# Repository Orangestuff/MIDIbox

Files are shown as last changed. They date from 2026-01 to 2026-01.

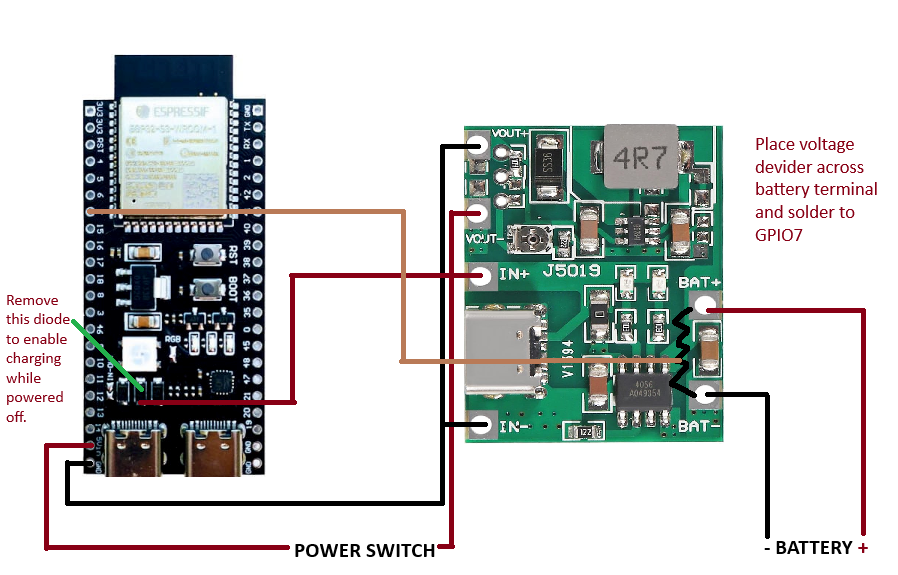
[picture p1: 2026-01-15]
images/schematic.png

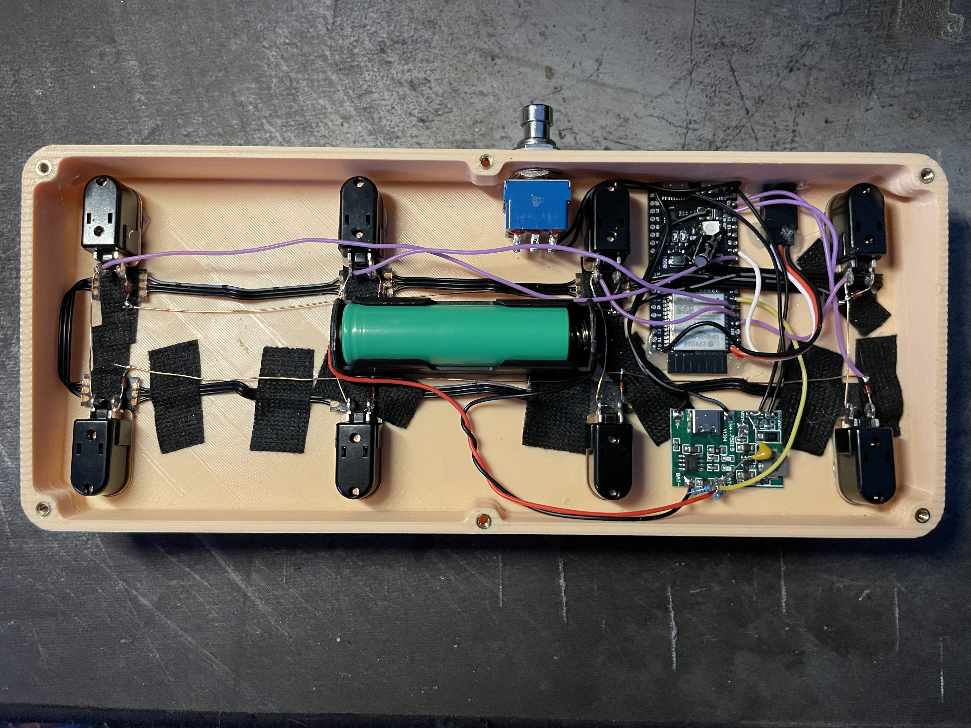
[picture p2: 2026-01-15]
images/build.JPG

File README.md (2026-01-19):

# ESP32-S3 Wireless MIDI Pedal

A fully programmable, battery-powered MIDI Foot Controller based on the ESP32-S3. This device supports **Bluetooth LE MIDI** and **USB MIDI** simultaneously, features a responsive **Web Interface** for configuration, and includes advanced **Power Management** for long battery life.

## 🚀 Key Features

### Connectivity

* **1000Hz Polling Rate:** Optimized "Fast Loop" architecture ensures ~1ms latency for note triggers.
* **Dual MIDI Interface:** Works over **Bluetooth LE (BLE)** and **USB** simultaneously.
* **Wireless Configuration:** Hosts a WiFi Access Point (`MidiBox_Config`) for on-the-fly editing via any smartphone or laptop.
* **Unique Identity Generation:** Hold **Switch 5 + Switch 8** on boot to generate a new BLE MAC address (useful for resolving pairing conflicts).

### Control & Logic

* **4 Programmable Banks:** Although the pedal has 8 physical footswitches, the software treats it as a 32-button controller divided into 4 "Pages" or "Banks". 
* **Advanced Switch Actions:**
* **Triggers:** Short Press, Long Press, and Release actions.
* **Message Types:** Note On/Off, CC, PC, Bank Up/Down, Direct Bank Select.
* **Logic Master:** Switches can trigger "None" (no MIDI) while still controlling other switches via groups.
* **Toggle Mode:** Latching behavior for CC or Note messages.

* **Grouping System:**
* **Exclusive Groups (Ex):** Pressing a switch turns OFF other switches in the same group (e.g., for channel switching).
* **Master/Slave Groups (Ld):** A "Master" switch can turn ON/OFF a defined set of "Slave" switches automatically.

### Expression Pedal

* **Per-Bank Configuration:** Different CC mappings and curves for every bank.
* **Smart Calibration:** "Set to Current" buttons in the Web UI for instant Min/Max calibration.
* **Response Curves:** Linear, Logarithmic (Fast Start), and Exponential (Swell).
* **Jitter Suppression:** Oversampling, hysteresis, and smoothing filters for stable output.

### Power & Presets

* **Deep Sleep:** Automatic low-power mode after inactivity.
* **Instant Wake:** Wakes up immediately upon pressing any footswitch.
* **Configurable:** Enable/Disable and set Timeout (1-120 mins) via Web UI.

* **Preset Manager:** Save and Load up to **5 Full Device Snapshots** (Setlists) to internal flash memory.
* **Battery Monitor:** Real-time voltage reading and low-battery LED warning.

---

## 🛠️ Hardware Bill of Materials (BOM)

| Component | Quantity | Description |
| --- | --- | --- |
| **Microcontroller** | 1 | ESP32-S3 DevKit (or similar S3 board) |
| **PSU/Battery Charger** | 1 | TP4056 Charger Module (or similar) |
| **Footswitches** | 8 | Momentary SPST Footswitches |
| **Power Switch** | 1 | Any SPST toggle switch |
| **LEDs** | 8 | WS2812B (Neopixel) individual LEDs or strip segments |
| **Expression Jack** | 1 | Servo extension wire |
| **Battery** | 1 | 3.7V 18650 Battery |
| **Resistors** | 3 | 2x100kΩ (For Battery Voltage Divider) 1x10kΩ (For Expression Pedal Pulldown) |
| **Diodes** | 8 | 1N4148 (For Switch Matrix - Optional but recommended) |
| **Enclosure** | 1 | 3D Printed Case (Files included in `/stl` folder) |
| **Threaded Inserts** | 6 | M3x4x5 Threaded Inserts (For pedalCaseV2.STL) |

## 🛠 Wiring & Pinout

The code is configured for an **ESP32-S3** using a 2x4 Switch Matrix.

| Component | ESP32-S3 Pin | Notes |
| --- | --- | --- |
| **Switch Row 1** | GPIO 12 | Matrix Output |
| **Switch Row 2** | GPIO 13 | Matrix Output |
| **Switch Col 1** | GPIO 4 | Matrix Input (Pull-up) |
| **Switch Col 2** | GPIO 5 | Matrix Input (Pull-up) |
| **Switch Col 3** | GPIO 6 | Matrix Input (Pull-up) |
| **Switch Col 4** | GPIO 8 | Matrix Input (Pull-up) |
| **LED Strip** | GPIO 48 | WS2812B / NeoPixel (9 LEDs) |
| **Battery Sense** | GPIO 7 | Voltage Divider (ADC1 Ch 6) |
| **Expression** | GPIO 2 | TRS Tip (ADC1 Ch 2) |

> **LED Wiring Note:** The LEDs require a "Snake" wiring pattern for the default mapping:
> `Sw1 -> Sw2 -> Sw3 -> Sw4 -> Sw8 -> Sw7 -> Sw6 -> Sw5`

**Note:** The Expression Pedal input expects a voltage divider setup (3.3V -> Pot -> GND, Wiper to GPIO 2).

## ⚡ Optional Hardware Mod: Offline Charging

By default, the ESP32 draws power and boots up whenever a USB cable is connected, even if the intention is only to charge the battery.

To enable **Offline Charging** (charging the battery via USB while the main unit remains powered down), you can remove the VBUS blocking diode (typically labeled **D1** or similar on the PCB).

* **Action:** Desolder and remove the Schottky diode on the 5V rail.
* **Result:** The USB connection will power the battery management circuit exclusively. The ESP32 will not boot until the main power switch is toggled ON.

## 🖨️ 3D Printed Case

This repository includes STL files for a custom enclosure designed to fit the electronics and switches perfectly.

* **pedalCaseV2.STL:** Holds all electronics.
* **baseplateV2.STL:** mount with M3 screws and threaded inserts.
* 
---

## 💾 Installation

1. **Environment:** Requires **ESP-IDF v5.x** (Tested with v5.5.1).
2. **Dependencies:**
* `tinyusb` (Component via IDF Component Manager)
* `driver/rtc_io` (Standard in IDF)

3. **Configuration:**
* Enable **TinyUSB** in `menuconfig`.
* Set partition table to accommodate NVS data (factory/app partitions).

4. **Flash:**
```bash
idf.py build flash monitor

```

---

## 📖 User Manual

### 1. Basic Operation

* **Power On:** The LEDs will flash the current Bank Color.
* **Change Banks:** Use configured "Bank Up/Down" switches or bind banks directly.
* *Bank 1: Red | Bank 2: Green | Bank 3: Blue | Bank 4: Purple*

* **Battery Status:** LED 1 indicates level:
* 🟢 > 3.9V (Good)
* 🟡 > 3.6V (Okay)
* 🔴 < 3.6V (Low)

### 2. Configuration Mode (WiFi)

1. If no known WiFi is found, the pedal broadcasts an Access Point:
* **SSID:** `MidiBox_Config`
* **Pass:** `12345678`

2. Connect your phone/laptop to this network.
3. Open a browser to `http://192.168.4.1`.
4. **Important:** Changes made in the UI are live in RAM. Click **"Save All Configuration"** to persist them to flash.

### 3. Preset Manager

Located in the Web UI:

* **Save:** Enter a name in the text box and click **SAVE**. This takes a snapshot of the *current* state (Bank settings, Expressions, etc.) and stores it in a slot.
* **Load:** Select a preset from the dropdown and click **LOAD**. The pedal immediately reconfigures itself.
* *Note: The browser remembers your last used preset ID for convenience.*

### 4. Deep Sleep

* The device sleeps after the configured idle time (Default: 5 mins).
* **To Wake:** simply step on **ANY** switch. The pedal wakes instantly and flashes the LEDs to confirm readiness.
* **Optimization:** The startup sequence prioritizes LED feedback before initializing WiFi/USB, making the wake-up feel instantaneous.

---

## 🧩 Advanced Logic Guide

The Web UI allows complex interactions between switches using **Masks**:

* **Exclusive Mask (Ex / 🛡️):**
* Assign switches to a "Group Number" (1-8).
* If Switch A and Switch B share Group 1, pressing A will automatically turn B **OFF**.
* *Usage: Guitar Amp Channel switching (Clean vs Distortion).*

* **Lead/Master Mask (Ld / ⚡):**
* If Switch A is the "Master" of Group 1, and Switch B "Includes" (🔗) Group 1...
* Pressing A will force B to turn **ON**.
* Releasing A (or turning it off) will force B to turn **OFF**.
* *Usage: A "Solo" switch that turns on Delay + Boost + Reverb simultaneously.*

---

## 📂 Project Structure

* `main.c` - Core logic, BLE stack, USB stack, GPIO matrix scanning, Sleep logic.
* `index.h` - HTML/CSS/JS for the Web Interface (gzipped string or raw string).
* `CMakeLists.txt` - Build configuration.

---

## ⚠️ Troubleshooting

* **Pedal won't wake up:** Ensure battery is charged (>3.0V).
* **Cannot find Bluetooth:** Hold **Switch 5 + 8** while powering on to generate a new MAC address. The LEDs will flash purple.
* **Expression Pedal Jitter:** Increase `EXP_HYSTERESIS` in `main.c` or use the Web UI to re-calibrate Min/Max values.
* **"Save Error" in Web UI:** Ensure you are not spamming the save button; writing to NVS takes ~200-500ms.

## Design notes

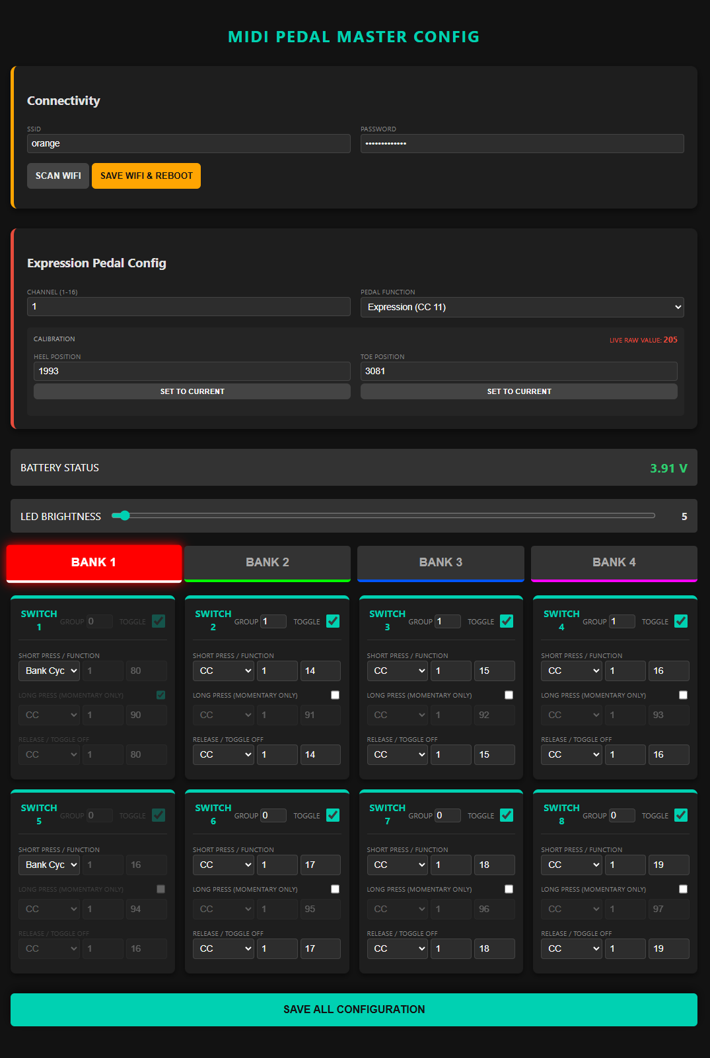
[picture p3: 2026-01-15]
images/config.png

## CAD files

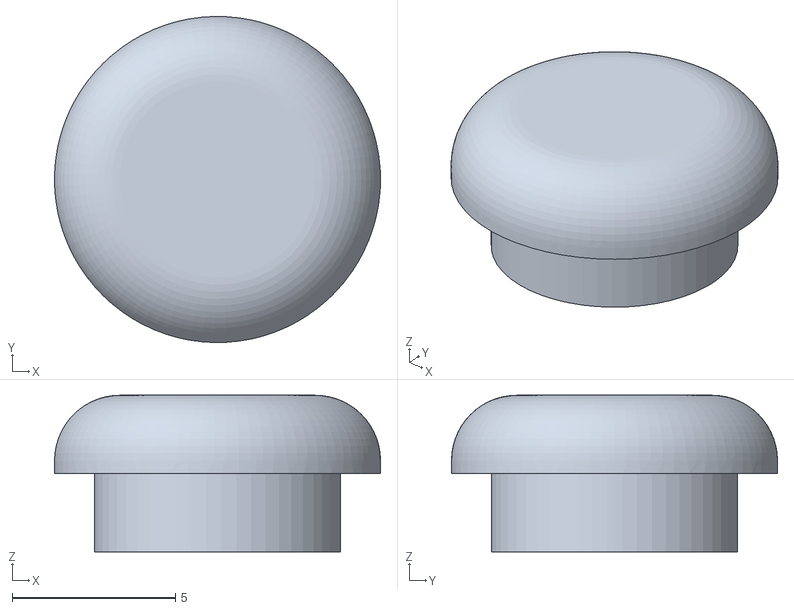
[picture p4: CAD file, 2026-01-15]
stl/LEDwindow.STL
10.0 x 10.00 x 4.80

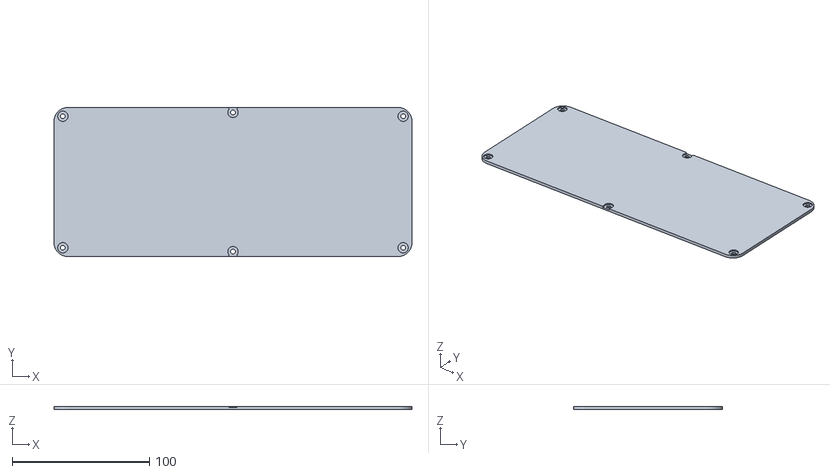
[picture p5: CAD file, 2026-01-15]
stl/baseplateV2.STL
260.5 x 108.4 x 2.40

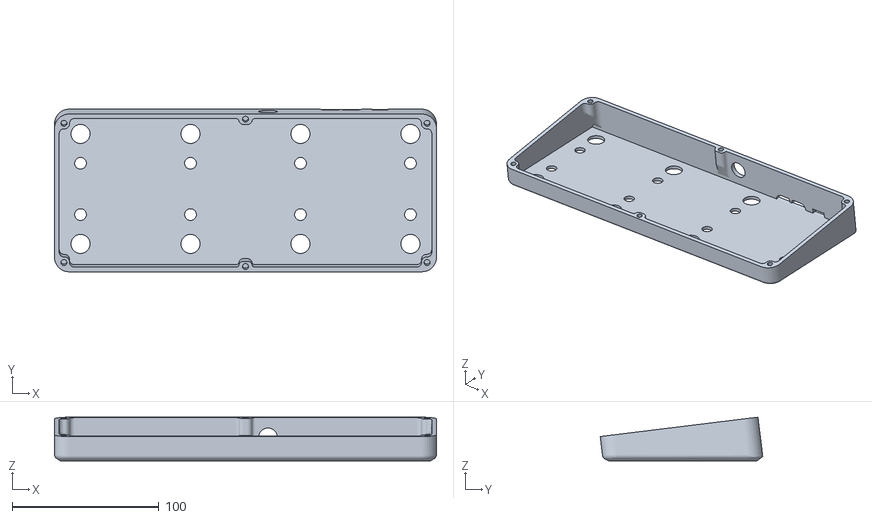
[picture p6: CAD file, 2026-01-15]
stl/pedalCaseV2.STL
260.5 x 110.9 x 29.8

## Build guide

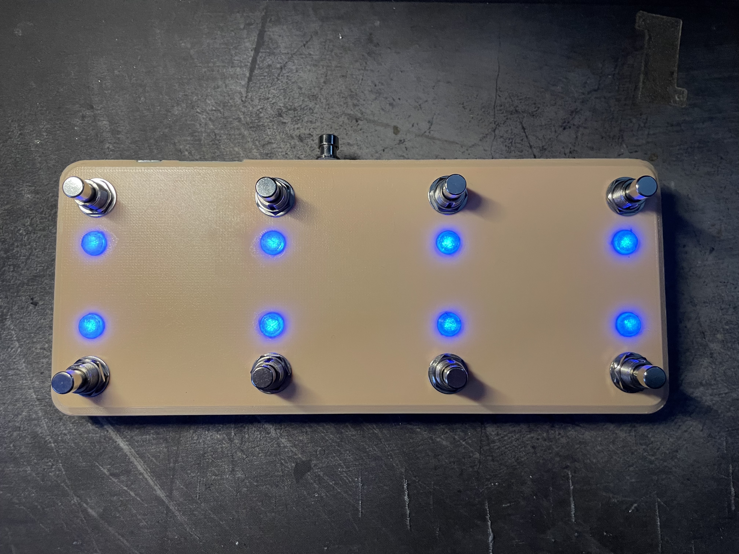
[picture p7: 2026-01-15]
images/build2.JPG

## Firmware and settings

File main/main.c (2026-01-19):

#include <stdio.h>
#include <string.h>
#include <stdlib.h>
#include <ctype.h>
#include <math.h>
#include <sys/param.h>

#include "esp_wifi.h"
#include "esp_http_server.h"
#include "esp_log.h"
#include "nvs_flash.h"
#include "driver/gpio.h"
#include "driver/rmt.h"
#include "tinyusb.h"
#include "tinyusb_default_config.h"
#include "cJSON.h"
#include "index.h"
#include "freertos/queue.h"
#include "freertos/event_groups.h"
#include "esp_system.h"
#include "esp_random.h"
#include "esp_mac.h"
#include "esp_timer.h"
#include "esp_sleep.h" // NEW: Required for Deep Sleep
#include "driver/rtc_io.h"
// --- ADC Headers ---
#include "esp_adc/adc_oneshot.h"

// --- BLE Headers ---
#include "esp_bt.h"
#include "esp_bt_main.h"
#include "esp_gap_ble_api.h"
#include "esp_gatts_api.h"
#include "esp_bt_defs.h"

static const char *TAG = "MIDI_PEDAL";

// --- CONFIGURATION ---
#define SWITCH_COUNT 8
#define BANK_COUNT 4
#define LONG_PRESS_MS 1200
#define DEEP_SLEEP_TIMEOUT_MS 30000 //30000 NEW: 5 Minutes
#define MIDI_NOTE_OFF 128
#define MIDI_NOTE_ON  144
#define MIDI_CC       176
#define MIDI_PC       192

#define LED_DATA_PIN 48
#define LED_COUNT 9
#define BATTERY_LED_INDEX 0

// --- EXPRESSION PEDAL CONFIG ---
#define EX_PEDAL_CHANNEL ADC_CHANNEL_2 
#define EX_SMOOTH_SIZE   10
#define EXP_HYSTERESIS   15

// --- BATTERY CONFIG (GPIO 7 / ADC1) ---
#define BAT_ADC_CHANNEL ADC_CHANNEL_6 
#define BAT_ADC_UNIT    ADC_UNIT_1    
#define BAT_DIVIDER_RATIO 2.0f 
#define BAT_MAX_V 4.2f
#define BAT_MIN_V 3.0f

#define WIFI_CONNECTED_BIT BIT0
#define WIFI_FAIL_BIT      BIT1
#define COMBO_HOLD_MS 2000

// --- MATRIX CONFIG ---
#define NUM_ROWS 2
#define NUM_COLS 4

const gpio_num_t ROW_PINS[NUM_ROWS] = { GPIO_NUM_12, GPIO_NUM_13 };
const gpio_num_t COL_PINS[NUM_COLS] = { GPIO_NUM_4, GPIO_NUM_5, GPIO_NUM_6, GPIO_NUM_8};

const int MATRIX_MAP[NUM_ROWS][NUM_COLS] = {
    {0, 1, 2, 3}, 
    {4, 5, 6, 7}  
};

// --- BLE MIDI UUIDs ---
#define MIDI_SERVICE_UUID        0x03, 0xB8, 0x0E, 0x5A, 0xED, 0xE8, 0x4B, 0x33, 0xA7, 0x51, 0x6C, 0xE3, 0x4E, 0xC4, 0xC7, 0x00
#define MIDI_CHARACTERISTIC_UUID 0x77, 0x72, 0xE5, 0xDB, 0x38, 0x68, 0x41, 0x12, 0xA1, 0xA9, 0xF2, 0x66, 0x9D, 0x10, 0x6B, 0xF3

// --- GLOBALS ---
uint8_t led_strip_pixels[LED_COUNT][3];
static float g_bat_voltage = 0.0f;
static volatile bool is_scanning = false; 
static esp_bd_addr_t current_mac_addr; 
static adc_oneshot_unit_handle_t adc_handle = NULL;
static float smoothed_bat = 0.0f;
static uint32_t last_activity_time = 0; // NEW: Activity Timer

volatile int g_exp_raw_val = 0; 

typedef struct { char ssid[32]; char pass[64]; } wifi_cfg_t;

// --- STRUCTS ---

typedef struct {
    uint8_t chan;
    uint8_t cc;
    uint16_t min;   
    uint16_t max;   
    uint8_t curve;  
} exp_cfg_t;

typedef struct { 
    uint8_t p_type; uint8_t p_chan; uint8_t p_d1; uint8_t p_edge;
    uint8_t lp_type; uint8_t lp_chan; uint8_t lp_d1; 
    uint8_t l_type; uint8_t l_chan; uint8_t l_d1; 
    
    uint8_t p_excl; uint8_t p_master; 
    uint8_t lp_excl; uint8_t lp_master;
    uint8_t l_excl; uint8_t l_master;

    uint8_t incl_mask; 
    uint8_t lp_enabled; 
    uint8_t toggle_mode; 
} sw_cfg_t;

typedef struct {
    sw_cfg_t switches[SWITCH_COUNT];
    exp_cfg_t exp; 
} bank_cfg_t;

typedef struct {
    uint8_t current_bank;
    uint8_t global_brightness;
    uint8_t sw6_cycle_rev;
    uint8_t sw7_cycle_fwd;
    uint8_t deep_sleep_en; 
    uint8_t deep_sleep_mins; 
    bank_cfg_t banks[BANK_COUNT];
} device_cfg_t; 

wifi_cfg_t w_cfg;
volatile device_cfg_t dev_cfg; 
static QueueHandle_t save_queue = NULL;
static EventGroupHandle_t s_wifi_event_group;
static httpd_handle_t srv = NULL;
static bool is_wifi_on = false;

//Preset Struct
#define MAX_PRESETS 5
typedef struct {
    char name[32];
    bool active;
    device_cfg_t data; // Stores the entire device state
} preset_t;
preset_t presets[MAX_PRESETS];
const uint8_t BANK_COLORS[4][3] = { {255,0,0}, {0,255,0}, {0,0,255}, {255,0,255} };

// Forward Declarations
void nvs_save_presets_to_flash();
void midi_task(void *pv);
void restart_task(void *p);
void wifi_init_task(void *pv); 
esp_err_t get_page(httpd_req_t *req);
esp_err_t get_json(httpd_req_t *req);
esp_err_t get_status(httpd_req_t *req);
esp_err_t post_save(httpd_req_t *req);
esp_err_t post_set_bank(httpd_req_t *req);
esp_err_t post_save_wifi(httpd_req_t *req);
esp_err_t get_wifi_scan(httpd_req_t *req);
void set_pixel(int index, uint8_t r, uint8_t g, uint8_t b);
void refresh_leds();
void set_wifi_mode(bool enable);
void init_battery();
void read_battery();
void send_midi_msg(uint8_t type, uint8_t chan, uint8_t val, uint8_t velocity);
static void wifi_event_handler(void* arg, esp_event_base_t event_base, int32_t event_id, void* event_data);

// --- USB DESCRIPTORS ---
enum { ITF_NUM_MIDI = 0, ITF_NUM_MIDI_STREAMING, ITF_COUNT };
enum { EPNUM_MIDI = 1 };
#define TUSB_DESCRIPTOR_TOTAL_LEN (TUD_CONFIG_DESC_LEN + TUD_MIDI_DESC_LEN)
static const char* s_str_desc[5] = {(char[]){0x09, 0x04}, "TinyUSB", "MidiBox", "123456", "MIDI Interface"};
static const uint8_t s_midi_cfg_desc[] = {
    TUD_CONFIG_DESCRIPTOR(1, ITF_COUNT, 0, TUSB_DESCRIPTOR_TOTAL_LEN, 0x00, 100),
    TUD_MIDI_DESCRIPTOR(ITF_NUM_MIDI, 4, EPNUM_MIDI, 0x80 | EPNUM_MIDI, 64),
};

// ==========================================================
//             BATTERY & EXPRESSION LOGIC (ADC1)
// ==========================================================
void init_battery() {
    adc_oneshot_unit_init_cfg_t init_config = { .unit_id = BAT_ADC_UNIT };
    if (adc_handle == NULL) {
        adc_oneshot_new_unit(&init_config, &adc_handle);
    }
    if (adc_handle) {
        adc_oneshot_chan_cfg_t config = { .bitwidth = ADC_BITWIDTH_DEFAULT, .atten = ADC_ATTEN_DB_12 };
        adc_oneshot_config_channel(adc_handle, BAT_ADC_CHANNEL, &config);
        
        int raw = 0;
        if (adc_oneshot_read(adc_handle, BAT_ADC_CHANNEL, &raw) == ESP_OK) {
            float pin_voltage = (raw / 4095.0f) * 3.3f; 
            smoothed_bat = pin_voltage * BAT_DIVIDER_RATIO;
        }
    }
}

void init_expression_pedal() {
    if (adc_handle == NULL) {
        adc_oneshot_unit_init_cfg_t init_config = { .unit_id = BAT_ADC_UNIT };
        adc_oneshot_new_unit(&init_config, &adc_handle);
    }
    
    if (adc_handle) {
        adc_oneshot_chan_cfg_t config = {
            .bitwidth = ADC_BITWIDTH_12, 
            .atten = ADC_ATTEN_DB_12,    
        };
        adc_oneshot_config_channel(adc_handle, EX_PEDAL_CHANNEL, &config);
    }
}

void read_battery() {
    if (adc_handle == NULL) return;
    int raw = 0;
    if (adc_oneshot_read(adc_handle, BAT_ADC_CHANNEL, &raw) == ESP_OK) {
        float pin_voltage = (raw / 4095.0f) * 3.3f; 
        float instant_voltage = pin_voltage * BAT_DIVIDER_RATIO;
        if (smoothed_bat < 0.1f) smoothed_bat = instant_voltage; 
        else smoothed_bat = (smoothed_bat * 0.98f) + (instant_voltage * 0.02f);
        g_bat_voltage = smoothed_bat;
    }
}

// Helper for Curve Math
uint8_t apply_curve(float normalized, uint8_t type) {
    float val = normalized;
    if (val < 0.0f) val = 0.0f;
    if (val > 1.0f) val = 1.0f;

    switch(type) {
        case 1: val = val * val; break;
        case 2: val = sqrtf(val); break;
        case 0: default: break;
    }
    return (uint8_t)(val * 127.0f);
}

// Change the function signature to accept the time
void process_expression_pedal(uint32_t now_ms) {
    volatile exp_cfg_t *exp = &dev_cfg.banks[dev_cfg.current_bank].exp;

    // ... [Keep ADC reading, Hysteresis, Smoothing, and Normalization code exactly the same] ...
    // ... [Copy lines 240-275 from your current file here] ...
    
    // Oversampling
    uint32_t sum = 0;
    int sample = 0;
    for(int i=0; i<4; i++) {
        adc_oneshot_read(adc_handle, EX_PEDAL_CHANNEL, &sample);
        sum += sample;
    }
    int raw = sum / 4;

    // Hysteresis
    static int stable_raw = 0;
    if (raw > (stable_raw + EXP_HYSTERESIS)) { stable_raw = raw - EXP_HYSTERESIS; } 
    else if (raw < (stable_raw - EXP_HYSTERESIS)) { stable_raw = raw + EXP_HYSTERESIS; }

    // Smoothing
    static float smooth_raw = 0;
    smooth_raw = (smooth_raw * 0.90f) + ((float)stable_raw * 0.10f);
    int current_val = (int)smooth_raw;

    // Update UI Global
    g_exp_raw_val = current_val; 

    // Normalize
    float norm = 0.0f;
    if (exp->max > exp->min) {
        norm = (float)(current_val - exp->min) / (float)(exp->max - exp->min);
    } else {
        norm = (float)(exp->min - current_val) / (float)(exp->min - exp->max);
    }
    if (norm < 0.0f) norm = 0.0f;
    if (norm > 1.0f) norm = 1.0f;

    uint8_t midi_val = apply_curve(norm, exp->curve);

    static uint8_t last_exp_val = 255;
    static uint8_t last_bank_idx = 255; 

    if (midi_val != last_exp_val || dev_cfg.current_bank != last_bank_idx) {
        send_midi_msg(176, exp->chan, exp->cc, midi_val); 
        last_exp_val = midi_val;
        last_bank_idx = dev_cfg.current_bank;
        
        // FIX: Use the synchronized time passed from the main loop
        last_activity_time = now_ms;
    }
}

// ==========================================================
//             BLE MIDI STACK
// ==========================================================
static bool is_ble_connected = false;
static uint16_t current_conn_id = 0;        
static esp_gatt_if_t current_gatts_if = 0;
static uint16_t midi_char_handle = 0; 

static const uint8_t midi_service_uuid[16] = { 0x00, 0xC7, 0xC4, 0x4E, 0xE3, 0x6C, 0x51, 0xA7, 0x33, 0x4B, 0xE8, 0xED, 0x5A, 0x0E, 0xB8, 0x03 };
static const uint8_t midi_char_uuid[16]    = { 0xF3, 0x6B, 0x10, 0x9D, 0x66, 0xF2, 0xA9, 0xA1, 0x12, 0x41, 0x68, 0x38, 0xDB, 0xE5, 0x72, 0x77 };

enum { MIDI_IDX_SVC, MIDI_IDX_CHAR, MIDI_IDX_VAL, MIDI_IDX_CFG, MIDI_IDX_NB };

static esp_ble_adv_params_t adv_params = {
    .adv_int_min        = 0x20,
    .adv_int_max        = 0x40,
    .adv_type           = ADV_TYPE_IND,
    .own_addr_type      = BLE_ADDR_TYPE_RANDOM, 
    .channel_map        = ADV_CHNL_ALL,
    .adv_filter_policy  = ADV_FILTER_ALLOW_SCAN_ANY_CON_ANY,
};

static uint8_t raw_adv_data[3 + 18] = { 0x02, 0x01, 0x06, 0x11, 0x07 }; 
static uint8_t raw_scan_rsp_data[] = { 0x08, 0x09, 'M', 'I', 'D', 'I', 'B', '0', 'X'};

#define CHAR_DECLARATION_SIZE   (sizeof(uint8_t))
static const uint16_t primary_service_uuid = ESP_GATT_UUID_PRI_SERVICE;
static const uint16_t character_declaration_uuid = ESP_GATT_UUID_CHAR_DECLARE;
static const uint16_t character_client_config_uuid = ESP_GATT_UUID_CHAR_CLIENT_CONFIG;
static const uint8_t char_prop_read_notify_write_nr = ESP_GATT_CHAR_PROP_BIT_READ | ESP_GATT_CHAR_PROP_BIT_NOTIFY | ESP_GATT_CHAR_PROP_BIT_WRITE_NR;
static const uint8_t ccc_value[2] = {0x00, 0x00}; 
static const uint8_t char_value[5] = {0x80, 0x80, 0x00, 0x00, 0x00}; 

static const esp_gatts_attr_db_t midi_gatt_db[MIDI_IDX_NB] = {
    [MIDI_IDX_SVC] = {{ESP_GATT_AUTO_RSP}, {ESP_UUID_LEN_16, (uint8_t *)&primary_service_uuid, ESP_GATT_PERM_READ, ESP_UUID_LEN_128, ESP_UUID_LEN_128, (uint8_t *)midi_service_uuid}},
    [MIDI_IDX_CHAR] = {{ESP_GATT_AUTO_RSP}, {ESP_UUID_LEN_16, (uint8_t *)&character_declaration_uuid, ESP_GATT_PERM_READ, CHAR_DECLARATION_SIZE, CHAR_DECLARATION_SIZE, (uint8_t *)&char_prop_read_notify_write_nr}},
    [MIDI_IDX_VAL] = {{ESP_GATT_AUTO_RSP}, {ESP_UUID_LEN_128, (uint8_t *)midi_char_uuid, ESP_GATT_PERM_READ | ESP_GATT_PERM_WRITE, 512, sizeof(char_value), (uint8_t *)char_value}},
    [MIDI_IDX_CFG] = {{ESP_GATT_AUTO_RSP}, {ESP_UUID_LEN_16, (uint8_t *)&character_client_config_uuid, ESP_GATT_PERM_READ | ESP_GATT_PERM_WRITE, sizeof(uint16_t), sizeof(ccc_value), (uint8_t *)ccc_value}},
};

static void gap_event_handler(esp_gap_ble_cb_event_t event, esp_ble_gap_cb_param_t *param) {
    switch (event) {
        case ESP_GAP_BLE_ADV_DATA_RAW_SET_COMPLETE_EVT: esp_ble_gap_start_advertising(&adv_params); break;
        case ESP_GAP_BLE_ADV_START_COMPLETE_EVT: if(param->adv_start_cmpl.status == ESP_BT_STATUS_SUCCESS) ESP_LOGI(TAG, "Legacy Advertising Started"); break;
        case ESP_GAP_BLE_SEC_REQ_EVT: esp_ble_gap_security_rsp(param->ble_security.ble_req.bd_addr, true); break;
        case ESP_GAP_BLE_AUTH_CMPL_EVT: ESP_LOGI(TAG, "Auth Complete. Success: %d", param->ble_security.auth_cmpl.success); break;
        default: break;
    }
}

static void gatts_event_handler(esp_gatts_cb_event_t event, esp_gatt_if_t gatts_if, esp_ble_gatts_cb_param_t *param) {
    if (event == ESP_GATTS_REG_EVT) {
        current_gatts_if = gatts_if;
        esp_ble_gap_set_rand_addr(current_mac_addr);
        esp_ble_gap_set_device_name("MidiBox");
        memcpy(&raw_adv_data[5], midi_service_uuid, 16);
        esp_ble_gap_config_adv_data_raw(raw_adv_data, sizeof(raw_adv_data));
        esp_ble_gap_config_scan_rsp_data_raw(raw_scan_rsp_data, sizeof(raw_scan_rsp_data));
        esp_ble_gatts_create_attr_tab(midi_gatt_db, gatts_if, MIDI_IDX_NB, 0);
    }
    else if (event == ESP_GATTS_CREAT_ATTR_TAB_EVT) {
        if (param->add_attr_tab.status == ESP_GATT_OK) {
            midi_char_handle = param->add_attr_tab.handles[MIDI_IDX_VAL]; 
            esp_ble_gatts_start_service(param->add_attr_tab.handles[MIDI_IDX_SVC]);
        }
    }
    else if (event == ESP_GATTS_CONNECT_EVT) {
        current_conn_id = param->connect.conn_id;
        is_ble_connected = true;
                esp_ble_conn_update_params_t conn_params = {0};
        memcpy(conn_params.bda, param->connect.remote_bda, sizeof(esp_bd_addr_t));
        conn_params.min_int = 0x06; // 7.5ms (1.25ms units)
        conn_params.max_int = 0x0C; // 15ms
        conn_params.latency = 0;
        conn_params.timeout = 400;  // 4s
        esp_ble_gap_update_conn_params(&conn_params);
        ESP_LOGI(TAG, "BLE Connected");
    }
    else if (event == ESP_GATTS_DISCONNECT_EVT) {
        is_ble_connected = false;
        ESP_LOGI(TAG, "BLE Disconnected - Restarting Adv");
        esp_ble_gap_start_advertising(&adv_params);
    }
}
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
void app_main(void) {
    // 1. CRITICAL: Release holds so we can use the pins immediately
    gpio_hold_dis(GPIO_NUM_12); // Row 1
    gpio_hold_dis(GPIO_NUM_13); // Row 2
    
    // Deinit RTC on columns to hand control back to the Digital Mux
    rtc_gpio_deinit(GPIO_NUM_4);
    rtc_gpio_deinit(GPIO_NUM_5);
    rtc_gpio_deinit(GPIO_NUM_6);
    rtc_gpio_deinit(GPIO_NUM_8);

    // --- WAKEUP DIAGNOSTICS ---
    esp_sleep_wakeup_cause_t cause = esp_sleep_get_wakeup_cause();
    if (cause == ESP_SLEEP_WAKEUP_EXT1) {
        uint64_t mask = esp_sleep_get_ext1_wakeup_status();
        int pin = __builtin_ffsll(mask) - 1;
        ESP_LOGI(TAG, "WAKEUP: Woke from Deep Sleep! Trigger Pin: GPIO %d", pin);
    } else {
        ESP_LOGI(TAG, "WAKEUP: Normal Boot / Reset (Reason: %d)", cause);
    }
    
    esp_err_t err = nvs_flash_init();
    if (err == ESP_ERR_NVS_NO_FREE_PAGES || err == ESP_ERR_NVS_NEW_VERSION_FOUND) { 
        nvs_flash_erase(); 
        nvs_flash_init(); 
    }

    nvs_handle_t h; 
    bool load_dev_success = false, load_wifi_success = false;

    // --- IDENTITY MANAGEMENT START ---
    if(nvs_open("storage", NVS_READWRITE, &h) == ESP_OK) {
        size_t mac_sz = sizeof(current_mac_addr);
        if (nvs_get_blob(h, "bt_mac", current_mac_addr, &mac_sz) != ESP_OK) {
            esp_fill_random(current_mac_addr, 6);
            current_mac_addr[0] |= 0xC0; 
            nvs_set_blob(h, "bt_mac", current_mac_addr, sizeof(current_mac_addr));
            nvs_commit(h);
        }
        size_t sz = 0;
        if (nvs_get_blob(h, "dev_cfg", NULL, &sz) == ESP_OK && sz == sizeof(dev_cfg)) { 
            nvs_get_blob(h, "dev_cfg", (void*)&dev_cfg, &sz); 
            load_dev_success = true; 
        }
        size_t w_sz = sizeof(w_cfg);
        if (nvs_get_blob(h, "w_cfg", &w_cfg, &w_sz) == ESP_OK && w_sz == sizeof(w_cfg)) { 
            load_wifi_success = true; 
        }
        uint8_t mode = 0;
        if (nvs_get_u8(h, "wifi_mode", &mode) == ESP_OK) { 
            is_wifi_on = (mode == 1); 
        }
        nvs_close(h);
    } 
    // --- IDENTITY MANAGEMENT END ---
    nvs_load_presets_from_flash();
    if (!load_dev_success) {
        dev_cfg.current_bank = 0; dev_cfg.sw6_cycle_rev = 0; dev_cfg.sw7_cycle_fwd = 0; dev_cfg.global_brightness = 127; dev_cfg.deep_sleep_en = 1; dev_cfg.deep_sleep_mins = 5;
        // Loop through all banks to init switches AND expression defaults
        for(int b=0; b<BANK_COUNT; b++) {
            // Default Switches
            for(int i=0; i<SWITCH_COUNT; i++) {
                dev_cfg.banks[b].switches[i] = (sw_cfg_t){MIDI_CC, 0, 80+i, 0, MIDI_CC, 0, 90+i, MIDI_CC, 0, 80+i, 0, 0, 0, 0, 0, 0, 0, 0, 0}; 
            }
            // Default Expression (Per Bank)
            dev_cfg.banks[b].exp.chan = 0;
            dev_cfg.banks[b].exp.cc = 11;
            dev_cfg.banks[b].exp.min = 100;
            dev_cfg.banks[b].exp.max = 4000;
            dev_cfg.banks[b].exp.curve = 0;
        }
    }
    if (!load_wifi_success) { strcpy(w_cfg.ssid, "SSID"); strcpy(w_cfg.pass, "Password"); }

    save_queue = xQueueCreate(1, sizeof(uint8_t)); 
    xTaskCreate(nvs_save_task, "nvs_save", 3072, NULL, 1, NULL);
    
    // Init GPIO
    for(int i=0; i<NUM_ROWS; i++) {
        gpio_reset_pin(ROW_PINS[i]);
        gpio_set_direction(ROW_PINS[i], GPIO_MODE_OUTPUT);
        gpio_set_level(ROW_PINS[i], 1); // Start High
    }
    for(int i=0; i<NUM_COLS; i++) {
        gpio_reset_pin(COL_PINS[i]);
        gpio_set_direction(COL_PINS[i], GPIO_MODE_INPUT);
        gpio_set_pull_mode(COL_PINS[i], GPIO_PULLUP_ONLY);
    }
    
    // --- RESET IDENTITY (COMBO BTN 5 + BTN 8 ON BOOT) ---
    bool btn5_pressed = false;
    bool btn8_pressed = false;
    
    gpio_set_level(ROW_PINS[1], 0); // Activate Row 2
    esp_rom_delay_us(10);
    if(gpio_get_level(COL_PINS[0]) == 0) btn5_pressed = true; // Btn 5
    if(gpio_get_level(COL_PINS[3]) == 0) btn8_pressed = true; // Btn 8
    gpio_set_level(ROW_PINS[1], 1);

    if (btn5_pressed && btn8_pressed) {
        ESP_LOGW(TAG, "COMBO HELD ON BOOT: Generating NEW Identity...");
        esp_fill_random(current_mac_addr, 6);
        current_mac_addr[0] |= 0xC0;
        if(nvs_open("storage", NVS_READWRITE, &h) == ESP_OK) {
            nvs_set_blob(h, "bt_mac", current_mac_addr, sizeof(current_mac_addr));
            nvs_commit(h); nvs_close(h);
        }
        rmt_config_t config = RMT_DEFAULT_CONFIG_TX(LED_DATA_PIN, RMT_CHANNEL_0); 
        config.clk_div = 4; 
        rmt_config(&config); 
        rmt_driver_install(config.channel, 0, 0);
        // Flash Purple to confirm
        for(int k=0; k<10; k++) { 
            for(int j=0; j<LED_COUNT; j++) set_pixel(j, 255, 0, 255);
            refresh_leds();
            vTaskDelay(pdMS_TO_TICKS(100)); 
            for(int j=0; j<LED_COUNT; j++) set_pixel(j, 0, 0, 0);
            refresh_leds();
            vTaskDelay(pdMS_TO_TICKS(100)); 
        }
        // De-init RMT so midi_task can load it properly later
        rmt_driver_uninstall(config.channel);
    }

    init_battery(); 
    init_expression_pedal();

    tinyusb_config_t tusb_cfg = TINYUSB_DEFAULT_CONFIG(); 
    tusb_cfg.descriptor.string = s_str_desc; 
    tusb_cfg.descriptor.string_count = 5; 
    tusb_cfg.descriptor.full_speed_config = s_midi_cfg_desc;
    tinyusb_driver_install(&tusb_cfg);

    s_wifi_event_group = xEventGroupCreate(); 
    esp_netif_init(); 
    esp_event_loop_create_default();
    esp_netif_create_default_wifi_sta(); 
    esp_netif_create_default_wifi_ap();
    wifi_init_config_t wcfg = WIFI_INIT_CONFIG_DEFAULT(); 
    esp_wifi_init(&wcfg);
    esp_wifi_set_ps(WIFI_PS_NONE);

    esp_event_handler_instance_register(WIFI_EVENT, ESP_EVENT_ANY_ID, &wifi_event_handler, NULL, NULL);
    esp_event_handler_instance_register(IP_EVENT, IP_EVENT_STA_GOT_IP, &wifi_event_handler, NULL, NULL);
    
    // --- FORCE AP IF NOT CONFIGURED ---
    if (strcmp(w_cfg.ssid, "SSID") == 0) {
        ESP_LOGI(TAG, "Default Credentials Detected. Forcing WiFi/AP Mode.");
        is_wifi_on = true; 
    }

    if (is_wifi_on) { 
        xTaskCreatePinnedToCore(wifi_init_task, "wifi_init", 4096, NULL, 10, NULL, 1); 
    } else { 
        init_ble_midi(); 
    }

    xTaskCreatePinnedToCore(midi_task, "midi", 4096, NULL, 5, NULL, 0);
}

// ... other variables ...
    uint32_t last_debounce_time[SWITCH_COUNT];
    bool sw_toggled_on[BANK_COUNT][SWITCH_COUNT] = {false};
    // NEW: Track which switch caused the flash
    int flash_source_sw_idx = -1;

// --- RECURSIVE TRIGGER OFF FUNCTION ---
// Handles the "Chain Reaction" for turning switches OFF.
// If Master2 turns off Master1, this function ensures Master1 also turns off its Slaves.
void trigger_switch_off(uint8_t bank, uint8_t idx) {
    
    // 1. Safety Check: If already OFF, do nothing (stops infinite loops)
    if (!sw_toggled_on[bank][idx]) return;

    // 2. Turn This Switch OFF
    sw_toggled_on[bank][idx] = false;
    sw_cfg_t *cfg = (sw_cfg_t*)&dev_cfg.banks[bank].switches[idx];
    
    // Send MIDI "Release/Off" Message
    send_midi_msg(cfg->l_type, cfg->l_chan, cfg->l_d1, 0);

    // 3. Recursive Cascade (Kill Slaves)
    // We use the Release Master Mask (l_master) to find slaves to kill.
    if (cfg->l_master > 0) {
        for (int b = 0; b < BANK_COUNT; b++) {
            for (int s = 0; s < SWITCH_COUNT; s++) {
                if (b == bank && s == idx) continue;
                
                sw_cfg_t *other = (sw_cfg_t*)&dev_cfg.banks[b].switches[s];

                // Do I lead this slave?
                if ((other->incl_mask & cfg->l_master) != 0) {
                    // RECURSIVE CALL: Kill the slave!
                    // This allows the off-signal to travel down the chain (MS2 -> MS1 -> SS)
                    trigger_switch_off(b, s);
                }
            }
        }
    }
}
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

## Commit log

2026-01-15 added stl files
    [baseplateV2.STL, pedalCaseV2.STL]
2026-01-15 added ledwindow stl file
    [LEDwindow.STL]
2026-01-15 added wiring image
2026-01-16 Update parts list and 3D case descriptions
    Updated resistor count and added threaded inserts in the parts list. Revised 3D printed case descriptions for clarity.
2026-01-16 Increase debounce time for button presses
    Increased debounce time for button press detection from 20ms to 50ms to improve reliability.
2026-01-16 Add group masks to switch configuration
    Added exclusive and inclusive group ID masks to switch configuration. Updated JSON handling to include new fields in serialization and deserialization.
2026-01-16 Enhance switch configuration with group logic
    Added support for inclusive group logic and master/slave functionality in toggle and momentary modes.
2026-01-16 Implement master switch in render function
    Added a master switch feature to the render function.
2026-01-16 Enhance momentary mode handling and add comments
    Added comments for clarity and fixed toggle state handling in momentary mode.
    [main.c]
2026-01-16 Refactor LED refresh logic and improve comments
    Refactor LED data handling and update comments for clarity.
2026-01-16 Update README.md with new features and grouping logic
    Revised the README.md to enhance the Features and Configuration sections, emphasizing the new Scene logic, Master/Slave architecture, and Global Bank interaction. Added an Advanced Grouping Logic sec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
2026-01-17 Refactor MIDI switch handling and LED logic
    Refactor MIDI switch handling and LED logic for better clarity and functionality.
2026-01-17 Refactor LED color handling in update_status_leds
    Refactor LED color calculation logic to use global brightness factor and improve readability.
2026-01-17 Enhance MIDI switch configuration and JSON handling
    Refactor MIDI switch configuration and handling, adding per-action grouping for press and release actions. Update JSON parsing and response to include new fields for switch configurations.
2026-01-17 Refactor switch handling and HTML generation
    Refactor switch handling logic and HTML structure for better readability and maintainability.
2026-01-17 Implement recursive switch off functionality
    Added a recursive function to handle turning switches off, ensuring that all dependent switches are also turned off. Updated existing trigger functions to utilize the new recursive off functionality 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
2026-01-18 Implement edge value selection for switches
    Added edge value handling for switches in the bank.
2026-01-18 Refactor process_expression_pedal function
    Refactor expression pedal processing for improved stability and smoothing.
    [main.c]
2026-01-18 Implement deep sleep and activity timer features
    Added deep sleep functionality and activity timer.
2026-01-18 Add power card for sleep settings and timeout input
    Added a power card section with auto-sleep settings and idle timeout input.
2026-01-19 Refactor preset handling and update device name
    Updated preset management and configuration settings.
2026-01-19 Implement preset manager and related UI controls
    Added a preset manager with load and save functionality, including UI elements for LED brightness and battery status.
2026-01-19 Add 1000Hz Polling Rate feature to README
    Added a feature highlighting the 1000Hz polling rate for optimized latency.
